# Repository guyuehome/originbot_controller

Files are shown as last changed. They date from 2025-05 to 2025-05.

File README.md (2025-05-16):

# OriginBot Open Source Intelligent Robot Suite (Controller Source Code Repository)

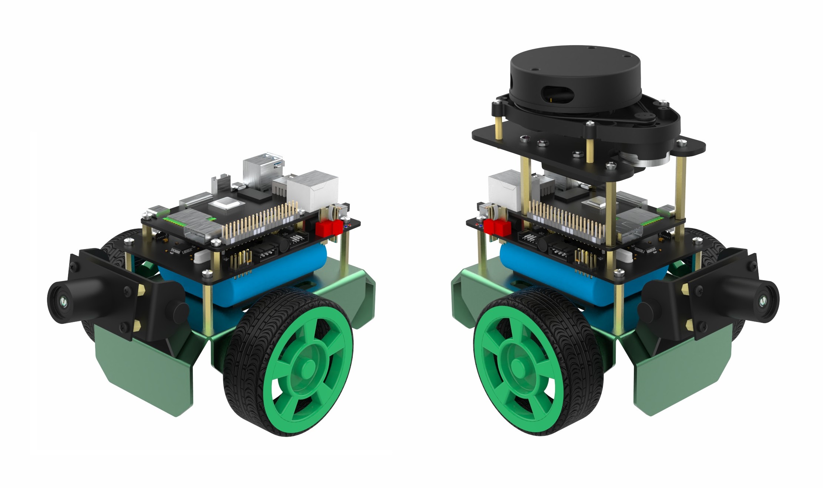
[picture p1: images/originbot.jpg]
originbot


OriginBot is an open-source intelligent robot suite and a community-driven open-source project aimed at enabling every participant to enjoy the fun of robot development.

## Project Links

### Main Website

[https://www.originbot.org/en/](https://www.originbot.org/en/)

### Source Code Repositories

| Repository | Description |
| --- | --- |
[originbot ](https://github.com/guyuehome/originbot)             | OriginBot robot function package repository |
[originbot_desktop](https://github.com/guyuehome/originbot_desktop) | OriginBot desktop function package repository |
[originbot_controller](https://github.com/guyuehome/originbot_controller) | OriginBot controller source code repository |

### Community Forum

[https://www.guyuehome.com/interlocution](https://www.guyuehome.com/interlocution)

## Software Architecture

- firmware: Precompiled controller firmware
- material: Electrical schematics, communication protocols, and other resources
- source: Controller source code project
- tools: Tools related to the controller

## Contributing

We sincerely invite developers to participate in the OriginBot project. There are many ways and forms to contribute:

### **Provide Feedback**

- If you encounter any issues or have suggestions while using the OriginBot suite, feel free to discuss them in the [Guyuehome Community Forum](https://guyuehome.com/Bubble/circleDetail/id/95);
- If you discover any bugs while using the OriginBot software, please submit an Issue in the [code repository](https://gitee.com/guyuehome/originbot);

### **Contribute Code**

- If you have optimizations, additions, or modifications to the native code while using the OriginBot suite, feel free to submit a Pull Request in the [code repository](https://gitee.com/guyuehome/originbot);

### **Spread Open Source**

- If you are interested in OriginBot, feel free to star the project's source code repository or share it with developers who might need it;
- If you create more interesting features or robots based on the OriginBot open-source project, feel free to share them in the [community forum](https://guyuehome.com/Bubble/circleDetail/id/95). Outstanding projects will also be promoted in the community.

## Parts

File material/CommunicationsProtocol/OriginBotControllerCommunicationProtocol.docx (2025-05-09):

OriginBot上下位机通讯协议

设计一个基于ROS2的驱动包，订阅cmd_vel话题实现对小车的控制、获取小车的里程计数据、陀螺仪数据。ROS2功能包使用串口和STM32驱动板实现通讯，现做出如下数据协议。

1. 驱动功能包程序向STM32驱动板发送电机速度控制数据，STM32驱动电机执行。数据协议如下：

帧头：0x55，帧头作为数据起始的标识，自定义0x55。

标识位：标识当前组数据是什么，0x01代表是速度控制指令。

长度：0x06，数据位共有6个字节数据，所以为0x06。数据位：负责左电机速度控制和右电机速度控制。

方向由0x00和0xFF两种模式，0x00速度值为负，0xFF速度值为正，当速度为0.00的情况下，方向值取0xFF。

速度单位为mm/s（8位）。

校验位：用于校验检测数据在传输的过程中是否出现数据错误。校验位数据计算公式如下：

校验位数值 = 数据位所有数据相加 & 0xFF

帧尾：0xBB，帧尾作为数据终止的标识，自定义0xBB。

通讯速度示例：左侧电机速度5mm/s，右电机速度-3mm/s

0x55 0x01 0x06 0xFF 0x05 0x00 0x00 0x03 0x00 0x07 0xBB

其中0xFF 0x50 0x00对应5mm/s；0x00 0x03 0x00对应-3mm/s。

校验位为

（0xFF + 0x05 + 0x00 + 0x00 + 0x03 + 0x00） & 0xFF = 0x07

2. STM32驱动板向驱动功能包发送电机速度反馈数据，驱动功能包节点根据该数据计算里程数据。数据协议如下：

解析内容同上。启动标识位为0x02标识速度反馈指令。

注：速度为0时，方向字段的数据可能是0x00或0xFF。

3. STM32驱动板向驱动功能包发送陀螺仪数据，驱动功能包阶段根据该数据发布imu话题。数据协议如下：

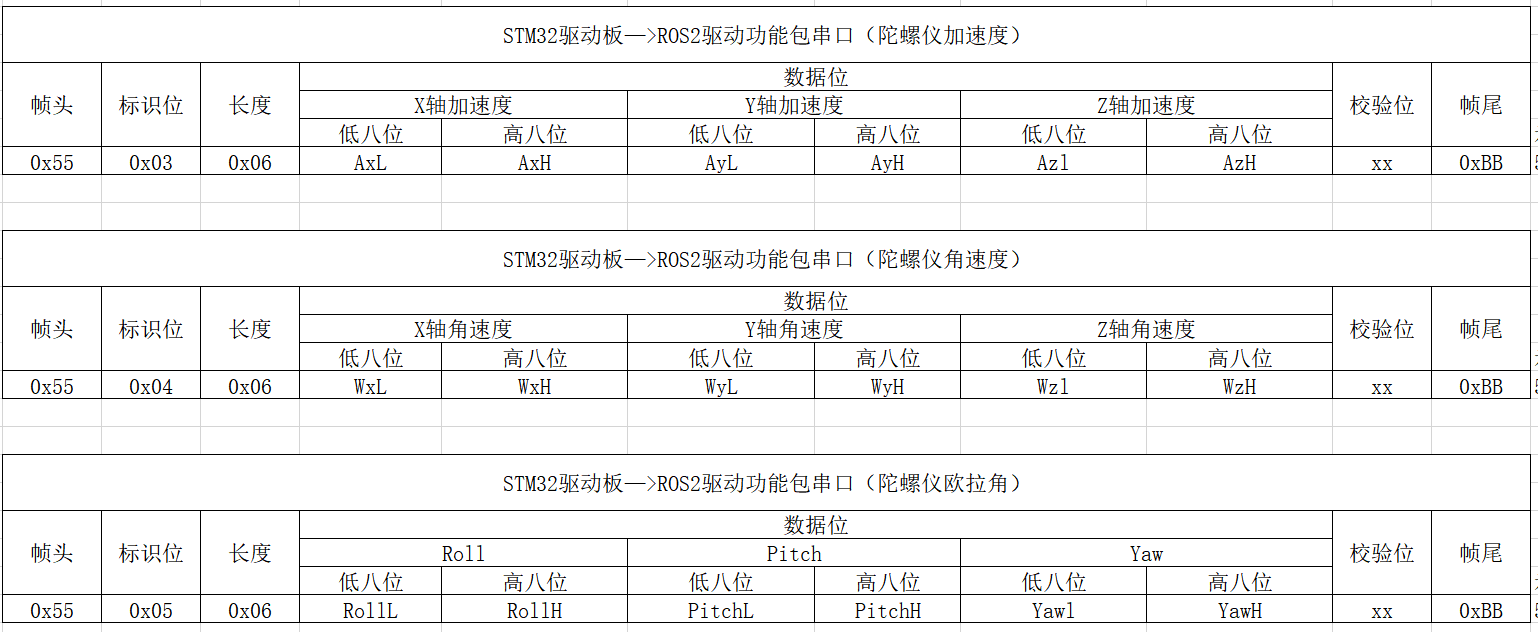
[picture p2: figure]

陀螺仪数据较多，这里分为三组分别传输。通过标识位来区分当前数据是什么。校验位的计算依旧是使用数据位各个数据相加 & 0xFF。

原始数据换算参考维特官方协议：

https://wit-motion.yuque.com/books/share/29a9c291-ebf5-4f6f-83e3-4093832dce78/locehn

加速度计算方式为：

ax=((AxH<<8)|AxL)/32768*16g(g 为重力加速度，可取 9.8m/s2)

ay=((AyH<<8)|AyL)/32768*16g(g 为重力加速度，可取 9.8m/s2)

az=((AzH<<8)|AzL)/32768*16g(g 为重力加速度，可取 9.8m/s2)

角速度计算方式为：

wx=((wxH<<8)|wxL)/32768*2000(°/s)

wy=((wyH<<8)|wyL)/32768*2000(°/s)

wz=((wzH<<8)|wzL)/32768*2000(°/s)

欧拉角计算方式为：

滚转角（x 轴）Roll=((RollH<<8)|RollL)/32768*180(°)

俯仰角（y 轴）Pitch=((PitchH<<8)|PitchL)/32768*180(°)

偏航角（z 轴）Yaw=((YawH<<8)|YawL)/32768*180(°)

说明：数据是按照16进制方式发送的，不是ASCII码。每个数据分低字节和高字节依次传送，二者组合成一个有符号的short 类型的数据。例如 X 轴加速度数据 Ax，其中 AxL 为低字节，AxH 为高字节。

转换方法如下：假设Data为实际的数据，DataH为其高字节部分，DataL为其低字节部分，那么：Data=((short)DataH<<8)|DataL。这里一定要注意 DataH 需要先强制转换为一个有符号的 short 类型的数据以后再移位，并且 Data 的数据类型也是有符号的short 类型，这样才能表示出负数。

欧拉角和四元数提供任意一个即可，若无法提供则一定要确保加速度和角速度的精度，欧拉角或者四元数将在ROS2功能包进行解算（最好由STM32完成）。

4. STM32驱动板向驱动功能包发送电压值数据，驱动功能包阶段根据该数据发布电压话题话题。数据协议如下：

电压值分整数和小数两部分发送，电压值=整数部分+小数部分/100，单位为V。

预留两个传感器数据位，没有使用时数据为0x00，校验计算同上。

5. 驱动功能包程序向STM32驱动板发送蜂鸣器、LED控制和imu校准指令，STM32驱动执行。数据协议如下：

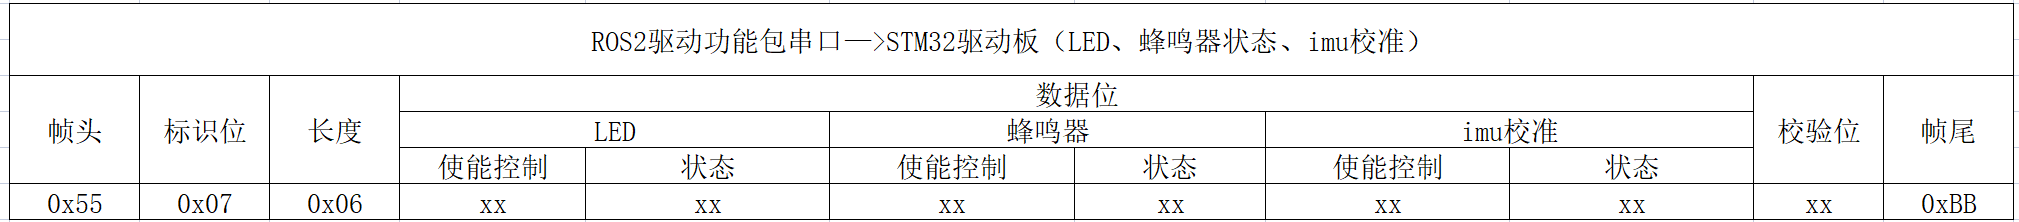
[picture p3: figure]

LED、蜂鸣器、imu校准指令的使能控制字段和状态字段可设置为零和非零值，校验计算同上。

使能控制字段非零时，状态字段的设置才能生效。LED、蜂鸣器和imu校准采用独立的使能控制和状态字段控制。

LED状态字段为零，则关闭LED；为非零，则打开LED。

蜂鸣器状态字段为零，则关闭蜂鸣器；为非零，则打开蜂鸣器。

imu校准状态字段为零，则无动作；为非零，则执行一次imu校准。

6. 驱动功能包程序向STM32驱动板发送PID参数，STM32驱动执行。数据协议如下：

PID参数作为外置预留，驱动板内置一组标定好的PID参数。

由于PID的数值较小，实际参数 = 数据字段/1000，校验计算同上。

7. 驱动板硬件资源

直流编码电机 *2

IMU陀螺仪 *1

蜂鸣器（高电平触发） *1

LED灯（高电平触发） *1

电压检测电路 *1

电源管理 *1

注：电源管理需具备5V 3A+的供电输出能力。

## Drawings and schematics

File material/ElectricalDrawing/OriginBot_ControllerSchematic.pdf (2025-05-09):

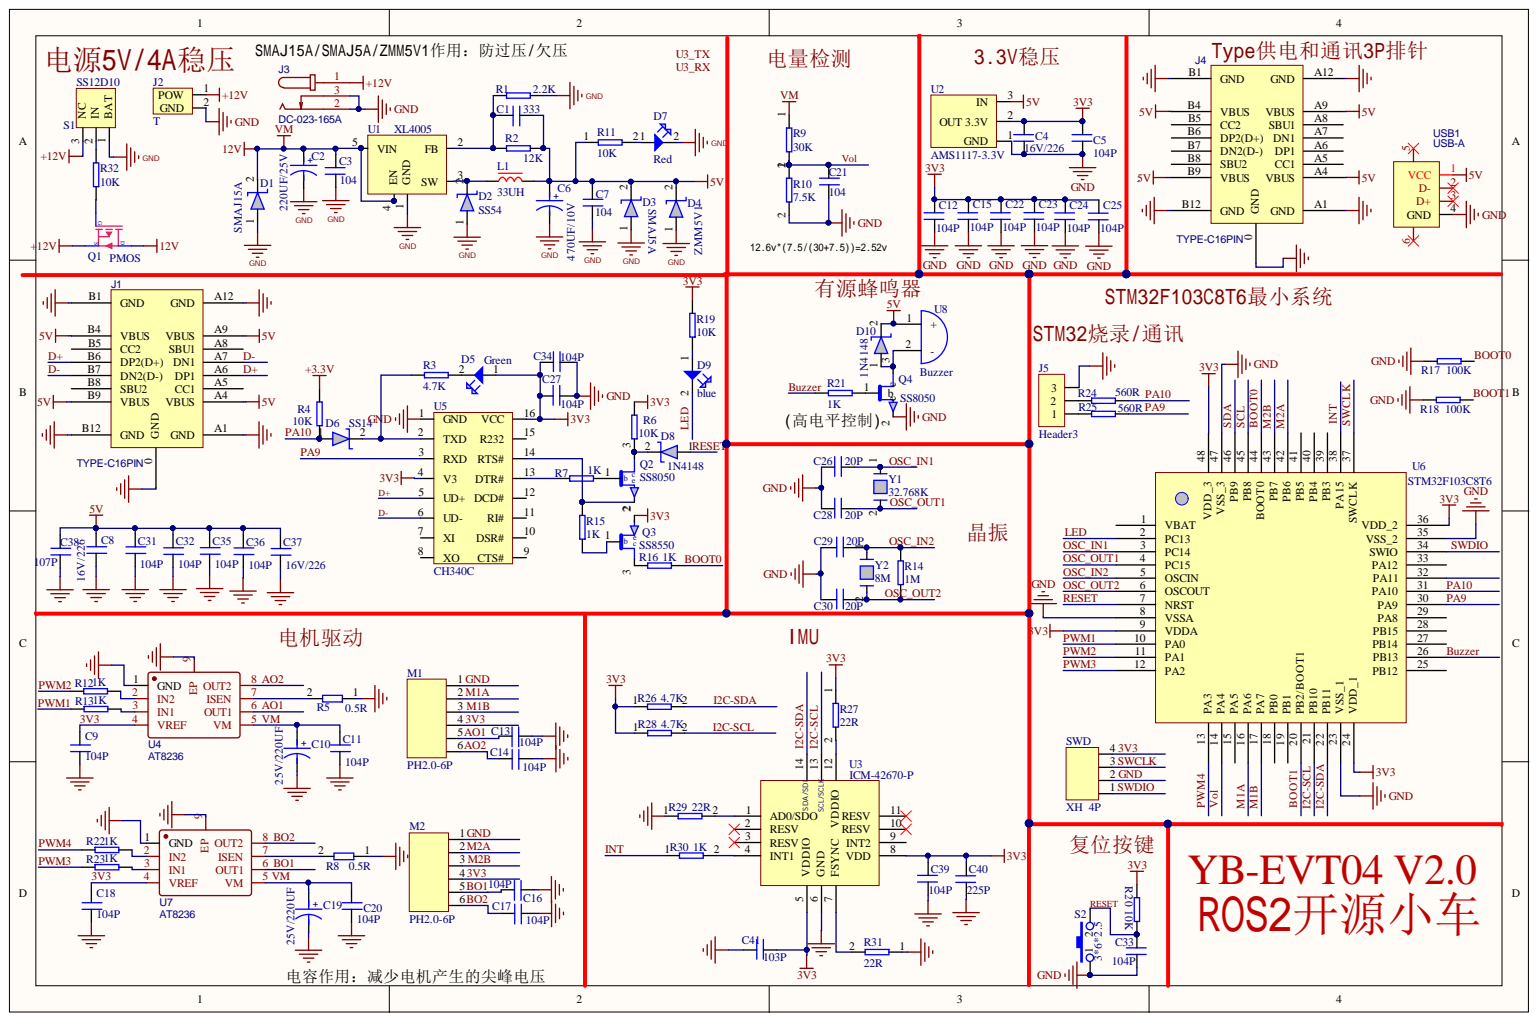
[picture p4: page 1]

GND GND GND

复位按键 | YB-EVT04 V2.0 ROS2开源小车

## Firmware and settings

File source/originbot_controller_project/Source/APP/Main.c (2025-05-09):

/***********************************************************************
Copyright (c) 2022, www.guyuehome.com

Licensed under the Apache License, Version 2.0 (the "License");
you may not use this file except in compliance with the License.
You may obtain a copy of the License at

? ? http://www.apache.org/licenses/LICENSE-2.0

Unless required by applicable law or agreed to in writing, software
distributed under the License is distributed on an "AS IS" BASIS,
WITHOUT WARRANTIES OR CONDITIONS OF ANY KIND, either express or implied.
See the License for the specific language governing permissions and
limitations under the License.
***********************************************************************/
#include <string.h>
#include <stdio.h>
#include "Main.h"
#include "UART1.h"
#include "UART3.h"
#include "delay.h"
#include "JY901.h"
#include "DIO.h"
#include "adc.h"
#include "bsp_icm42670P.h"
#include "app_imu_42670P.h"

int8_t imu_initflag = 1; //0:初始化成功
int8_t g_imu_dealflag = 0;

int main(void)
{
	int Call_10ms = 1;
  // 设置时钟频率
  SysTick_init(72, 10);

	// 初始化串口1，用于和主机通信
  UART1_Init(115200);

  // 注意delay_ms(ms)中，ms必须<=1864
  Delay_Ms(1000); Delay_Ms(1000);
  
  // 初始化ADC，用于读取电池电压
  Adc_Init();
  // 初始化GPIO，用于控制LED和蜂鸣器等
  GPIO_Config();
  // 初始化电机控制接口(PWM)
  MOTOR_GPIO_Init();
  // 设置不分频，PWM频率 72000000/3600=20khz
  Motor_PWM_Init(MOTOR_MAX_PULSE, MOTOR_FREQ_DIVIDE);
  // 初始化电机编码器接口
  Encoder_Init();
  // 初始化心跳包定时器
  TIM1_Init();
  // 初始化PID控制
  PID_Init();
  
	
	#if ENABLE_ICM42670P
	imu_initflag = icm42670_init();
	#else
  // 初始化串口3，用于读取陀螺仪数据
  UART3_Init(9600);

  // 等待陀螺仪初始化完成
	jy901_init();
	#endif
	
	Delay_Ms(1000);
  
  // printf("\n\nFirmware Version: V%d.%d\n", VERSION_MAJOR, VERSION_MINOR);h
  
  while (1) {
		
		if(g_imu_dealflag ==1) //imu数据处理
			{
				g_imu_dealflag = 0;
				get_icm_attitude();
			}
			
    // 接收、解析并响应主机发送的串口指令
    if (Is_Recv_New_Cmd()) {
      Parse_Cmd_Data(Get_RxBuffer(), Get_CMD_Length());
      Clear_CMD_Flag();
    }
    
    // 周期性上报数据给主机
    if (Timer_Get_Count(COUNT_BEAT_ID) == 0) {
      // 检测电池电压是否过低，电压过低，蜂鸣器报警
      if (!Bat_Update_Power_State())
        BUZZER_ON();  

      // 上报周期：40毫秒
      if ((Call_10ms % 4 + 1) == 1) {
        Motion_Send_Data(); // 电机速度
				
				#if ENABLE_ICM42670P 
						Acc_Send_Data_ICM42670P();// 陀螺仪 加速度
						Gyro_Send_Data_ICM42670P();// 陀螺仪 角速度
						Angle_Send_Data_ICM42670P();// 陀螺仪 角度
					#else
						Acc_Send_Data();    // 陀螺仪 加速度
						Gyro_Send_Data();   // 陀螺仪 角速度
						Angle_Send_Data();  // 陀螺仪 角度
					#endif
        
        Sensor_Send_Data(); // 电池电量
      }
      
      Call_10ms++;
      if (Call_10ms >= 8)
        Call_10ms = 0;

      Timer_Set_Count(COUNT_BEAT_ID, 1);
    }
  }
}

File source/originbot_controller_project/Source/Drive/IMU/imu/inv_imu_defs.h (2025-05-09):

/*
 *
 * Copyright (c) [2018] by InvenSense, Inc.
 * 
 * Permission to use, copy, modify, and/or distribute this software for any
 * purpose with or without fee is hereby granted.
 * 
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
 */

#ifndef _INV_IMU_DEFS_H_
#define _INV_IMU_DEFS_H_

#ifdef __cplusplus
extern "C" {
#endif

/** @file inv_imu_defs.h
 * File exposing the device register map
 */

#include <stdint.h>

#define INV_IMU_REV_A 0xA
#define INV_IMU_REV_B 0XB

/* Include device definition */
#include "imu/inv_imu.h"

#if INV_IMU_REV == INV_IMU_REV_A
#include "imu/inv_imu_regmap_rev_a.h"
#elif INV_IMU_REV == INV_IMU_REV_B
#include "imu/inv_imu_regmap_rev_b.h"
#endif

#define ACCEL_DATA_SIZE 6
#define GYRO_DATA_SIZE  6
#define TEMP_DATA_SIZE  2

#define FIFO_HEADER_SIZE              1
#define FIFO_ACCEL_DATA_SIZE          ACCEL_DATA_SIZE
#define FIFO_GYRO_DATA_SIZE           GYRO_DATA_SIZE
#define FIFO_TEMP_DATA_SIZE           1
#define FIFO_TS_FSYNC_SIZE            2
#define FIFO_TEMP_HIGH_RES_SIZE       1
#define FIFO_ACCEL_GYRO_HIGH_RES_SIZE 3

#define FIFO_16BYTES_PACKET_SIZE                                                                   \
	(FIFO_HEADER_SIZE + FIFO_ACCEL_DATA_SIZE + FIFO_GYRO_DATA_SIZE + FIFO_TEMP_DATA_SIZE +         \
	 FIFO_TS_FSYNC_SIZE)
#define FIFO_20BYTES_PACKET_SIZE                                                                   \
	(FIFO_HEADER_SIZE + FIFO_ACCEL_DATA_SIZE + FIFO_GYRO_DATA_SIZE + FIFO_TEMP_DATA_SIZE +         \
	 FIFO_TS_FSYNC_SIZE + FIFO_TEMP_HIGH_RES_SIZE + FIFO_ACCEL_GYRO_HIGH_RES_SIZE)

#define FIFO_HEADER_ODR_ACCEL 0x01
#define FIFO_HEADER_ODR_GYRO  0x02
#define FIFO_HEADER_FSYNC     0x04
#define FIFO_HEADER_TMST      0x08
#define FIFO_HEADER_HEADER_20 0x10
#define FIFO_HEADER_GYRO      0x20
#define FIFO_HEADER_ACC       0x40
#define FIFO_HEADER_MSG       0x80

#define INVALID_VALUE_FIFO                   ((int16_t)0x8000)
#define INVALID_VALUE_FIFO_1B                ((int8_t)0x80)
#define OUT_OF_BOUND_TEMPERATURE_NEG_FIFO_1B ((int8_t)0x81)
#define OUT_OF_BOUND_TEMPERATURE_POS_FIFO_1B ((int8_t)0x7F)

/** Describe the content of the FIFO header */
typedef union {
	unsigned char Byte;
	struct {
#if INV_IMU_IS_GYRO_SUPPORTED
		unsigned char gyro_odr_different : 1;
#else
		unsigned char reserved1 : 1;
#endif
		unsigned char accel_odr_different : 1;
#if INV_IMU_IS_GYRO_SUPPORTED
		unsigned char fsync_bit : 1;
#else
		unsigned char reserved2 : 1;
#endif
		unsigned char timestamp_bit : 1;
		unsigned char twentybits_bit : 1;
#if INV_IMU_IS_GYRO_SUPPORTED
		unsigned char gyro_bit : 1;
#else
		unsigned char reserved3 : 1;
#endif
		unsigned char accel_bit : 1;
		unsigned char msg_bit : 1;
	} bits;
} fifo_header_t;

/* ----------------------------------------------------------------------------
 * Device registers description
 *
 * Next section defines some of the registers bitfield and declare corresponding
 * accessors.
 * Note that descriptors and accessors are not provided for all the registers 
 * but only for the most useful ones.
 * For all details on registers and bitfields functionalities please refer to 
 * the device datasheet.
 * ---------------------------------------------------------------------------- */

/* ---------------------------------------------------------------------------
 * register bank 0 
 * ---------------------------------------------------------------------------- */

/*
 * DEVICE_CONFIG
 * Register Name : DEVICE_CONFIG
 */

/* SPI_MODE */
typedef enum {
	DEVICE_CONFIG_SPI_MODE_1_2 = (0x1 << DEVICE_CONFIG_SPI_MODE_POS),
	DEVICE_CONFIG_SPI_MODE_0_3 = (0x0 << DEVICE_CONFIG_SPI_MODE_POS),
} DEVICE_CONFIG_SPI_MODE_t;

/* SPI_AP_4WIRE */
typedef enum {
	DEVICE_CONFIG_SPI_4WIRE = (0x1 << DEVICE_CONFIG_SPI_AP_4WIRE_POS),
	DEVICE_CONFIG_SPI_3WIRE = (0x0 << DEVICE_CONFIG_SPI_AP_4WIRE_POS),
} DEVICE_CONFIG_SPI_AP_4WIRE_t;

/*
 * SIGNAL_PATH_RESET
 * Register Name: SIGNAL_PATH_RESET
 */

/* SOFT_RESET_DEVICE_CONFIG */
typedef enum {
	SIGNAL_PATH_RESET_SOFT_RESET_DEVICE_CONFIG_EN =
	    (0x01 << SIGNAL_PATH_RESET_SOFT_RESET_DEVICE_CONFIG_POS),
	SIGNAL_PATH_RESET_SOFT_RESET_DEVICE_CONFIG_DIS =
	    (0x00 << SIGNAL_PATH_RESET_SOFT_RESET_DEVICE_CONFIG_POS),
} SIGNAL_PATH_RESET_SOFT_RESET_DEVICE_CONFIG_t;

/* FIFO_FLUSH */
typedef enum {
	SIGNAL_PATH_RESET_FIFO_FLUSH_EN  = (0x01 << SIGNAL_PATH_RESET_FIFO_FLUSH_POS),
	SIGNAL_PATH_RESET_FIFO_FLUSH_DIS = (0x00 << SIGNAL_PATH_RESET_FIFO_FLUSH_POS),
} SIGNAL_PATH_RESET_FIFO_FLUSH_t;

/*
 * INT_CONFIG
 * Register Name: INT_CONFIG
 */

/* INT2_MODE */
typedef enum {
	INT_CONFIG_INT2_MODE_LATCHED = (0x01 << INT_CONFIG_INT2_MODE_POS),
	INT_CONFIG_INT2_MODE_PULSED  = (0x00 << INT_CONFIG_INT2_MODE_POS),
} INT_CONFIG_INT2_MODE_t;

/* INT2_DRIVE_CIRCUIT */
typedef enum {
	INT_CONFIG_INT2_DRIVE_CIRCUIT_PP = (0x01 << INT_CONFIG_INT2_DRIVE_CIRCUIT_POS),
	INT_CONFIG_INT2_DRIVE_CIRCUIT_OD = (0x00 << INT_CONFIG_INT2_DRIVE_CIRCUIT_POS),
} INT_CONFIG_INT2_DRIVE_CIRCUIT_t;
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

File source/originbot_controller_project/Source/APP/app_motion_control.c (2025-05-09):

/***********************************************************************
Copyright (c) 2022, www.guyuehome.com

Licensed under the Apache License, Version 2.0 (the "License");
you may not use this file except in compliance with the License.
You may obtain a copy of the License at

? ? http://www.apache.org/licenses/LICENSE-2.0

Unless required by applicable law or agreed to in writing, software
distributed under the License is distributed on an "AS IS" BASIS,
WITHOUT WARRANTIES OR CONDITIONS OF ANY KIND, either express or implied.
See the License for the specific language governing permissions and
limitations under the License.
***********************************************************************/
#include "app_motion_control.h"
#include "Main.h"
#include "UART1.h"

#include <math.h>
#include <stdio.h> 

// 小车刹车超时时间，单位为10ms
#define MAX_STOP_COUNT       3

// 左右轮电机PWM变量
int motorLeft = 0;
int motorRight = 0;

// 左右轮速度
int leftSpeedNow = 0;
int rightSpeedNow = 0;

// 左右轮速度设置
int leftSpeedSet = 0;
int rightSpeedSet = 0;

// 编码器10ms前后数据
int leftWheelEncoderNow = 0;
int rightWheelEncoderNow = 0;
int leftWheelEncoderLast = 0;
int rightWheelEncoderLast = 0;


// 累计编码器计数和准备上报速度
int left_encoder_cnt = 0;
int right_encoder_cnt = 0;
double left_speed_mm_s = 0;
double right_speed_mm_s = 0;
// 上报速度数据时记录的编码器进入10ms次数
int record_time=0;


char s_pwm_1[8];
void pid_debug_uartsend(int data_1,int data_2,int data_3) // DEBUG pid调参，通过串口直接发送pid中的设定值、反馈和输出，使用过空格分隔。使用此方法可以注释掉main中的所有发送部分方便上位机分析。
{
  sprintf(s_pwm_1, "%8d", data_1);
  for (int i = 0; i < 8; i++)
  {
    UART1_Put_Char(s_pwm_1[i]);
  }
  // UART1_Put_Char(0x40);
  UART1_Put_Char(0x20);

  sprintf(s_pwm_1, "%8d", data_2);
  for (int i = 0; i < 8; i++)
  {
    UART1_Put_Char(s_pwm_1[i]);
  }

  UART1_Put_Char(0x20);

  sprintf(s_pwm_1, "%8d", data_3);
  for (int i = 0; i < 8; i++)
  {
    UART1_Put_Char(s_pwm_1[i]);
  }

  UART1_Put_Char(0x0d);
  UART1_Put_Char(0x0a);
}

u32 g_start_count = 0;//记录开机的时间 
extern int8_t imu_initflag;
extern int8_t g_imu_dealflag;
// TIM1每10ms产生一次中断
void TIM1_UP_IRQHandler(void)
{
  // 检查是否发生中断事件
  if (TIM_GetITStatus(TIM1, TIM_IT_Update) != RESET) {
		
		g_start_count++;//10ms加一次
		//IMU相关
		if(imu_initflag == 0)
		{
			g_imu_dealflag = 1;
//			get_icm_attitude();
		}
		
    if (Timer_Get_Count(COUNT_BEAT_ID))
      Timer_Count_Auto_Reduce(COUNT_BEAT_ID);

    #if ENABLE_MOTION_CONTROL
    Motion_Control_10ms();
    #endif

    
    // 清除中断标志位
    TIM_ClearITPendingBit(TIM1, TIM_IT_Update);  
  }
}

// 实时计算小车运行速度
void Motion_Control_10ms(void)
{
  // 获取左右轮当前实际速度(mm/s)
  Get_Motor_Speed(&leftSpeedNow, &rightSpeedNow);

  if (leftSpeedSet || rightSpeedSet) 
  {
    // 目标速度
    pid_Task_Left.speedSet = leftSpeedSet;
    pid_Task_Right.speedSet = rightSpeedSet;
    // 实际速度
    pid_Task_Left.speedNow = leftSpeedNow;
    pid_Task_Right.speedNow = rightSpeedNow;

    // 执行PID控制
    Pid_Ctrl(&motorLeft, &motorRight, g_attitude.yaw);
    
    // 设置PWM
    Motion_Set_PWM(motorLeft, motorRight);
		
  } 
  else 
  {
    motorLeft = 0;
    motorRight = 0;
    Motion_Set_PWM(motorLeft, motorRight);
    reset_Uk(&pid_Task_Left);
    reset_Uk(&pid_Task_Right);
  }

}


void Motion_Set_PWM(int motor_Left, int motor_Right)
{
  Motor_Set_Pwm(MOTOR_ID_1, motor_Left);
  Motor_Set_Pwm(MOTOR_ID_2, motor_Right);
}



void Get_Motor_Speed(int *leftSpeed, int *rightSpeed)
{
  Encoder_Update_Count(ENCODER_ID_A);
  leftWheelEncoderNow = Encoder_Get_Count_Now(ENCODER_ID_A);
  Encoder_Update_Count(ENCODER_ID_B);
  rightWheelEncoderNow = Encoder_Get_Count_Now(ENCODER_ID_B);
  
 
  *leftSpeed = (leftWheelEncoderNow - leftWheelEncoderLast) * ENCODER_CNT_10MS_2_SPD_MM_S;
  *rightSpeed =(rightWheelEncoderNow - rightWheelEncoderLast)* ENCODER_CNT_10MS_2_SPD_MM_S;
  left_encoder_cnt += leftWheelEncoderNow - leftWheelEncoderLast;
  right_encoder_cnt += rightWheelEncoderNow - rightWheelEncoderLast;
  record_time++;
  // 记录上一周期的编码器数据
  leftWheelEncoderLast = leftWheelEncoderNow;
  rightWheelEncoderLast = rightWheelEncoderNow;
}




// 上报电机速度
void Motion_Send_Data(void)
{
  //计算本次上报时应当上报的速度
  left_speed_mm_s = left_encoder_cnt * ENCODER_CNT_10MS_2_SPD_MM_S / record_time;
  right_speed_mm_s = right_encoder_cnt * ENCODER_CNT_10MS_2_SPD_MM_S / record_time;
  record_time = 0;
  left_encoder_cnt = 0;
  right_encoder_cnt = 0;

  #define MotionLEN        7
  uint8_t data_buffer[MotionLEN] = {0};
  uint8_t i, checknum = 0;
  
  if (left_speed_mm_s < 0) {
    data_buffer[0] = 0x00;
    uint16_t spd = (uint16_t)fabs(left_speed_mm_s);
    data_buffer[1] = spd&0xFF;
    data_buffer[2] = (spd>>8)&0xFF;
  } else {
    data_buffer[0] = 0xFF;
    uint16_t spd = (uint16_t)left_speed_mm_s;
    data_buffer[1] = spd&0xFF;
    data_buffer[2] = (spd>>8)&0xFF;
  }

  if (right_speed_mm_s < 0) {
    data_buffer[3] = 0x00;
    uint16_t spd = (uint16_t)fabs(right_speed_mm_s);
    data_buffer[4] = spd&0xFF;
    data_buffer[5] = (spd>>8)&0xFF;
  } else {
    data_buffer[3] = 0xFF;
    uint16_t spd = (uint16_t)right_speed_mm_s;
    data_buffer[4] = spd&0xFF;
    data_buffer[5] = (spd>>8)&0xFF;
  }

  // 校验位的计算使用数据位各个数据相加 & 0xFF
  for (i = 0; i < MotionLEN - 1; i++)
    checknum += data_buffer[i];

  data_buffer[MotionLEN - 1] = checknum & 0xFF;
  UART1_Put_Char(0x55); // 帧头
  UART1_Put_Char(0x02); // 标识位
  UART1_Put_Char(0x06); // 数据位长度(字节数)
  
  UART1_Put_Char(data_buffer[0]);
  UART1_Put_Char(data_buffer[1]);
  UART1_Put_Char(data_buffer[2]);
  UART1_Put_Char(data_buffer[3]);
  UART1_Put_Char(data_buffer[4]);
  UART1_Put_Char(data_buffer[5]);
  UART1_Put_Char(data_buffer[6]);
  
  UART1_Put_Char(0xBB); // 帧尾
}



// 设置目标速度 此处set是pwm值
void Motion_Test_SpeedSet(uint8_t index_l, int16_t left , 
                          uint8_t index_r, int16_t right)
{
  // l_speed_diff=left-right;
  if (left > SPD_MM_S_MAX) 
    left = SPD_MM_S_MAX;
  if (right > SPD_MM_S_MAX) 
    right = SPD_MM_S_MAX;

  if (index_l == 0)
    leftSpeedSet = -left;
  else
    leftSpeedSet = left;
    
  if (index_r == 0)
    rightSpeedSet = -right;
  else
    rightSpeedSet = right;
}

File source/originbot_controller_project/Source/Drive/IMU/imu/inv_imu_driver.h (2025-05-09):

/*
 *
 * Copyright (c) [2018] by InvenSense, Inc.
 * 
 * Permission to use, copy, modify, and/or distribute this software for any
 * purpose with or without fee is hereby granted.
 * 
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
 */

/** @defgroup Driver Driver
 *  @brief High-level functions to drive the device
 *  @{
 */

/** @file inv_imu_driver.h */

#ifndef _INV_IMU_DRIVER_H_
#define _INV_IMU_DRIVER_H_

#ifdef __cplusplus
extern "C" {
#endif

#include "imu/inv_imu_defs.h"
#include "imu/inv_imu_transport.h"

/** Max FSR values for accel */
#define ACCEL_CONFIG0_FS_SEL_MAX ACCEL_CONFIG0_FS_SEL_16g
/** Max user offset value for accel (mg) */
#define ACCEL_OFFUSER_MAX_MG 1000
/** Accel start-up time */
#define ACC_STARTUP_TIME_US 10000

#if INV_IMU_IS_GYRO_SUPPORTED
/** Max FSR values for gyro */
#define GYRO_CONFIG0_FS_SEL_MAX GYRO_CONFIG0_FS_SEL_2000dps
/** Max user offset value for gyro (dps) */
#define GYRO_OFFUSER_MAX_DPS 64
/** Gyro start-up time */
#define GYR_STARTUP_TIME_US 70000
#endif

/** Max buffer size mirrored from FIFO at polling time */
#define FIFO_MIRRORING_SIZE 16 * 258 // packet size * max_count = 4kB

/** Sensor identifier for UI control function */
enum inv_imu_sensor {
	INV_SENSOR_ACCEL, /**< Accelerometer */
#if INV_IMU_IS_GYRO_SUPPORTED
	INV_SENSOR_GYRO, /**< Gyroscope */
	INV_SENSOR_FSYNC_EVENT, /**< FSYNC */
#else
	INV_SENSOR_RESERVED1,
	INV_SENSOR_RESERVED2,
#endif
	INV_SENSOR_TEMPERATURE, /**< Chip temperature */
	INV_SENSOR_DMP_PEDOMETER_EVENT, /**< Pedometer: step detected */
	INV_SENSOR_DMP_PEDOMETER_COUNT, /**< Pedometer: step counter */
	INV_SENSOR_DMP_TILT, /**< Tilt */
	INV_SENSOR_DMP_FF, /**< FreeFall */
	INV_SENSOR_DMP_LOWG, /**< Low G */
	INV_SENSOR_DMP_SMD, /**< Significant Motion Detection */
	INV_SENSOR_MAX
};

/** Configure FIFO usage */
typedef enum {
	INV_IMU_FIFO_DISABLED = 0, /**< FIFO is disabled and data source is sensors registers */
	INV_IMU_FIFO_ENABLED  = 1, /**< FIFO is used as data source */
} INV_IMU_FIFO_CONFIG_t;

/** Sensor event structure definition */
typedef struct {
	int      sensor_mask;
	uint16_t timestamp_fsync;
	int16_t  accel[3];
#if INV_IMU_IS_GYRO_SUPPORTED
	int16_t gyro[3];
#endif
	int16_t temperature;
	int8_t  accel_high_res[3];
#if INV_IMU_IS_GYRO_SUPPORTED
	int8_t gyro_high_res[3];
#endif
} inv_imu_sensor_event_t;

/** IMU driver states definition */
typedef struct inv_imu_device {
	/** Transport layer. 
	 *  @warning Must be the first one of inv_imu_device_t 
	 */
	inv_imu_transport_t transport;

	/** callback executed by:
	 *  * inv_imu_get_data_from_fifo (if FIFO is used).
	 *  * inv_imu_get_data_from_registers (if FIFO isn't used).
	 *  May be NULL if above API are not used by application 
	 */
	void (*sensor_event_cb)(inv_imu_sensor_event_t *event);

	uint8_t               fifo_data[FIFO_MIRRORING_SIZE]; /**< FIFO mirroring memory area */
	uint8_t               dmp_is_on; /**< DMP started status */
	uint8_t               endianness_data; /**< Data endianness configuration */
	uint8_t               fifo_highres_enabled; /**< Highres mode configuration */
	INV_IMU_FIFO_CONFIG_t fifo_is_used; /**< FIFO configuration */
#if INV_IMU_IS_GYRO_SUPPORTED
	uint64_t gyro_start_time_us; /**< Gyro start time to discard first samples */
#endif
	uint64_t accel_start_time_us; /**< Accel start time to discard first samples */
} inv_imu_device_t;

/** Interrupt enum state for INT1, INT2, and IBI */
typedef enum { INV_IMU_DISABLE = 0, INV_IMU_ENABLE } inv_imu_interrupt_value;

/** Interrupt definition */
typedef struct {
	inv_imu_interrupt_value INV_UI_FSYNC;
	inv_imu_interrupt_value INV_UI_DRDY;
	inv_imu_interrupt_value INV_FIFO_THS;
	inv_imu_interrupt_value INV_FIFO_FULL;
	inv_imu_interrupt_value INV_SMD;
	inv_imu_interrupt_value INV_WOM_X;
	inv_imu_interrupt_value INV_WOM_Y;
	inv_imu_interrupt_value INV_WOM_Z;
	inv_imu_interrupt_value INV_FF;
	inv_imu_interrupt_value INV_LOWG;
	inv_imu_interrupt_value INV_STEP_DET;
	inv_imu_interrupt_value INV_STEP_CNT_OVFL;
	inv_imu_interrupt_value INV_TILT_DET;
} inv_imu_interrupt_parameter_t;

/** @brief Initializes device.
 *  @param[in] s                Pointer to device.
 *  @param[in] serif            Pointer on serial interface structure.
 *  @param[in] sensor_event_cb  Callback executed when a new sensor event is available. *
 *  @return                     0 on success, negative value on error.
 */
int inv_imu_init(inv_imu_device_t *s, const struct inv_imu_serif *serif,
                 void (*sensor_event_cb)(inv_imu_sensor_event_t *event));

/** @brief Reset device by reloading OTPs.
 *  @param[in] s  Pointer to device.
 *  @return       0 on success, negative value on error.
 */
int inv_imu_device_reset(inv_imu_device_t *s);

/** @brief return WHOAMI value.
 *  @param[in] s          Pointer to device.
 *  @param[out] who_am_i  WHOAMI for device.
 *  @return 0 on success, negative value on error.
 */
int inv_imu_get_who_am_i(inv_imu_device_t *s, uint8_t *who_am_i);

/** @brief Enable/put accel in low power mode.
 *  @param[in] s  Pointer to device.
 *  @return       0 on success, negative value on error.
 */
int inv_imu_enable_accel_low_power_mode(inv_imu_device_t *s);

/** @brief Enable/put accel in low noise mode.
 *  @param[in] s  Pointer to device.
 *  @return       0 on success, negative value on error.
 */
int inv_imu_enable_accel_low_noise_mode(inv_imu_device_t *s);

/** @brief Disable all 3 axes of accel.
 *  @param[in] s  Pointer to device.
 *  @return       0 on success, negative value on error.
 */
int inv_imu_disable_accel(inv_imu_device_t *s);

/** @brief Configure accel Output Data Rate.
 *  @param[in] s          Pointer to device.
 *  @param[in] frequency  The requested frequency.
 *  @return               0 on success, negative value on error.
 */
int inv_imu_set_accel_frequency(inv_imu_device_t *s, const ACCEL_CONFIG0_ODR_t frequency);

/** @brief Set accel Low-Power averaging value.
 *  @param[in] s        Pointer to device.
 *  @param[in] acc_avg  Requested averaging value.
 *  @return             0 on success, negative value on error.
 */
int inv_imu_set_accel_lp_avg(inv_imu_device_t *s, ACCEL_CONFIG1_ACCEL_FILT_AVG_t acc_avg);

/** @brief Set accel Low-Noise bandwidth value.
 *  @param[in] s       Pointer to device.
 *  @param[in] acc_bw  Requested averaging value.
 *  @return            0 on success, negative value on error.
 */
int inv_imu_set_accel_ln_bw(inv_imu_device_t *s, ACCEL_CONFIG1_ACCEL_FILT_BW_t acc_bw);

/** @brief Set accel full scale range.
 *  @param[in] s            Pointer to device.
 *  @param[in] accel_fsr_g  Requested full scale range.
 *  @return                 0 on success, negative value on error.
 */
int inv_imu_set_accel_fsr(inv_imu_device_t *s, ACCEL_CONFIG0_FS_SEL_t accel_fsr_g);
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

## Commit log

2025-05-09 Refactor code structure for improved readability and maintainability
    [originbot_controller.PrjPcb, originbot_controller.SchDoc]
2025-05-16 Add documentation
    [OriginBotControllerCommunicationProtocol.xlsx, originbot_controller.PrjPcb, originbot_controller.SchDoc]
